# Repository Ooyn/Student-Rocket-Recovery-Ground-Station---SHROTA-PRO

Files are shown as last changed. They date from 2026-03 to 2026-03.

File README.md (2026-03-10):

# Student-Rocket-Recovery-Ground-Station---SHROTA-PRO
Shrota Pro is a custom-engineered, portable ground station PCB specifically designed to track and recover student-built rockets after touchdown. Acting as a specialized, relative GPS system, the handheld device receives critical telemetry data from the rocket and calculates its exact landing coordinates relative to the user's current position, making post-flight retrieval highly efficient.

At the heart of the system is an STM32 microcontroller responsible for real-time processing of incoming telemetry, parsing GPS data, managing sensor inputs, and driving the user interface. The board is powered by a 7.4V dual battery bus, utilizing step-down switching regulators to provide stable 5V and 3.3V rails. This robust power management ensures reliable operation of the MCU, sensitive RF equipment, and the onboard screen interface, allowing users to read relative distances and headings directly in the field. Standardized USB connectivity is also integrated for flashing firmware and serial debugging.

To accurately pinpoint positions, the board utilizes a multi-sensor navigation suite featuring an L89 GNSS module, a NEO-M8N GNSS module, and a BMM150 3-axis geomagnetic sensor that acts as a digital compass to determine the user's precise heading. For reliable long-range telemetry reception, the system incorporates a versatile radio block. It integrates RYLR998 and LLCC68 LoRa modules for robust, low-power communication links, alongside an RFD900x radio modem interface for extended range, ensuring the recovery team maintains a solid, line-of-sight connection to the downed rocket.

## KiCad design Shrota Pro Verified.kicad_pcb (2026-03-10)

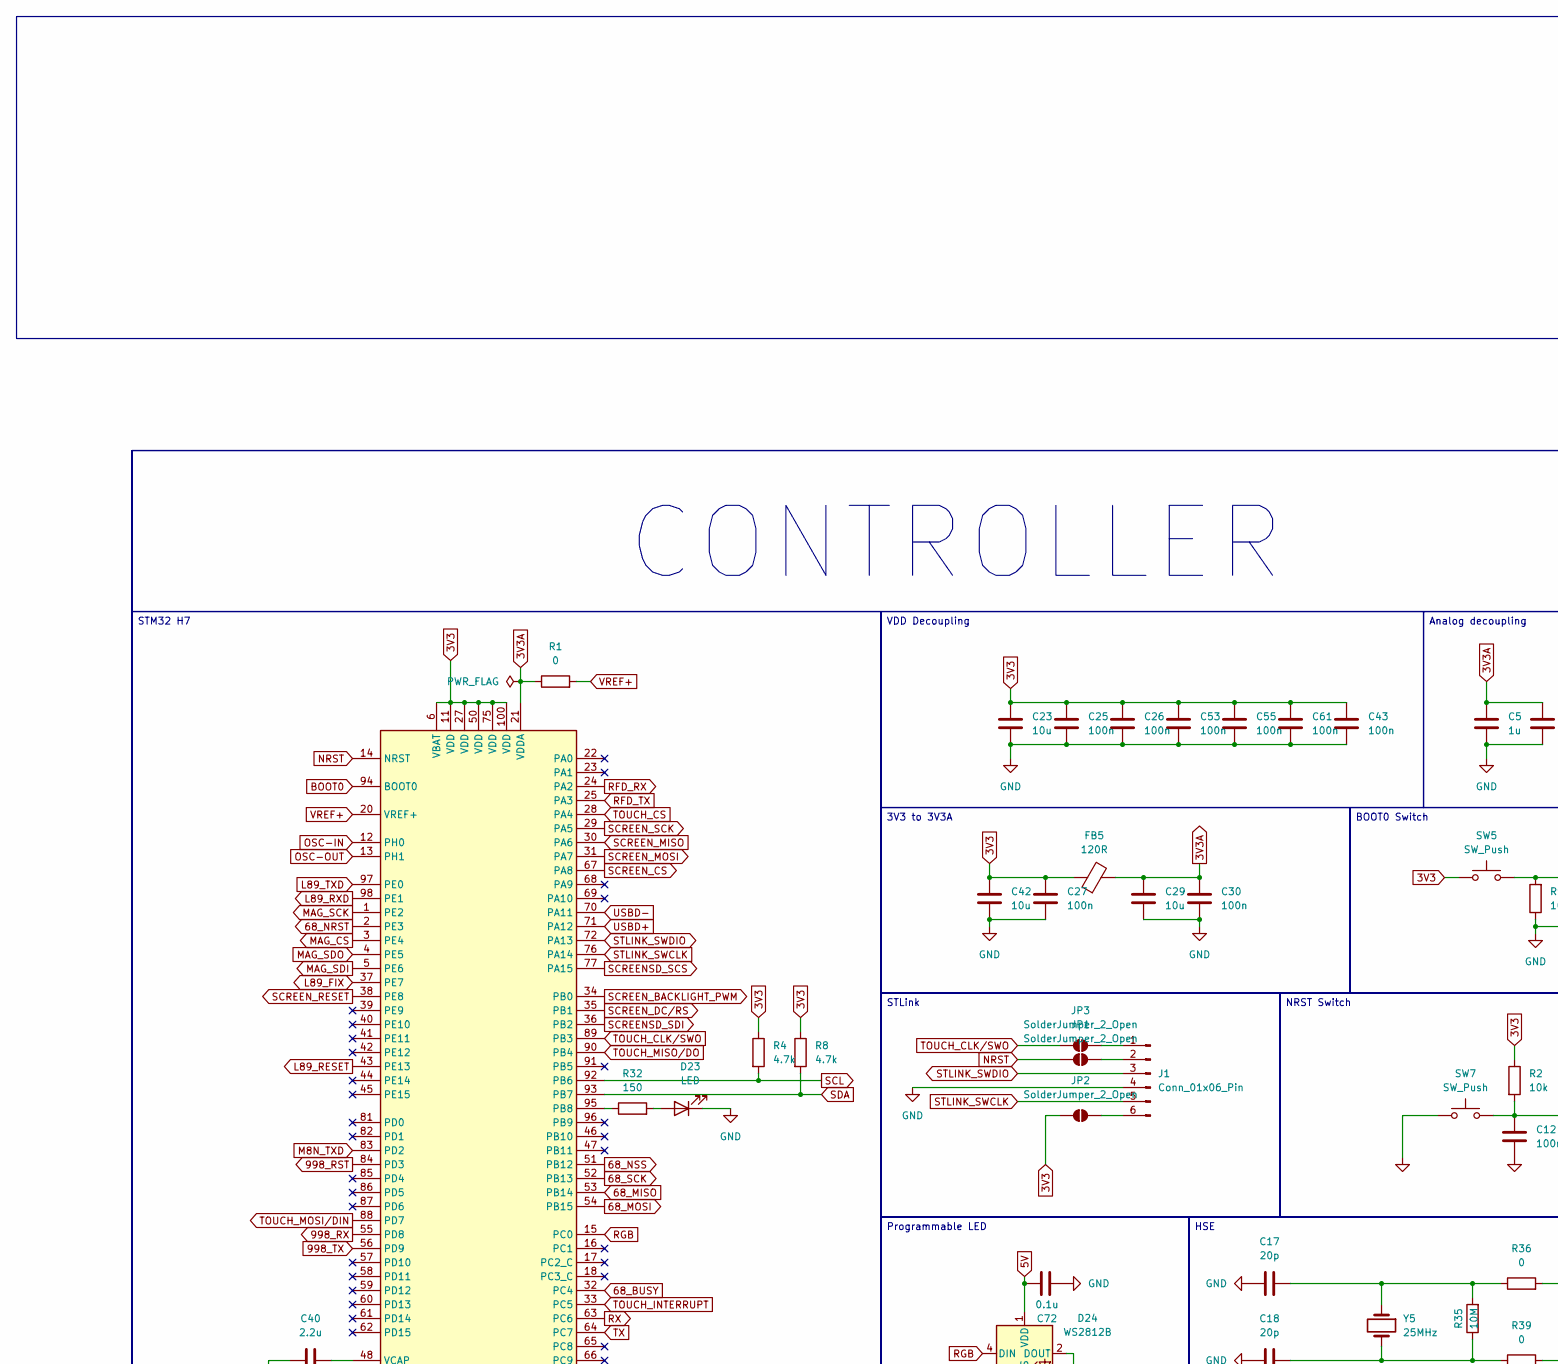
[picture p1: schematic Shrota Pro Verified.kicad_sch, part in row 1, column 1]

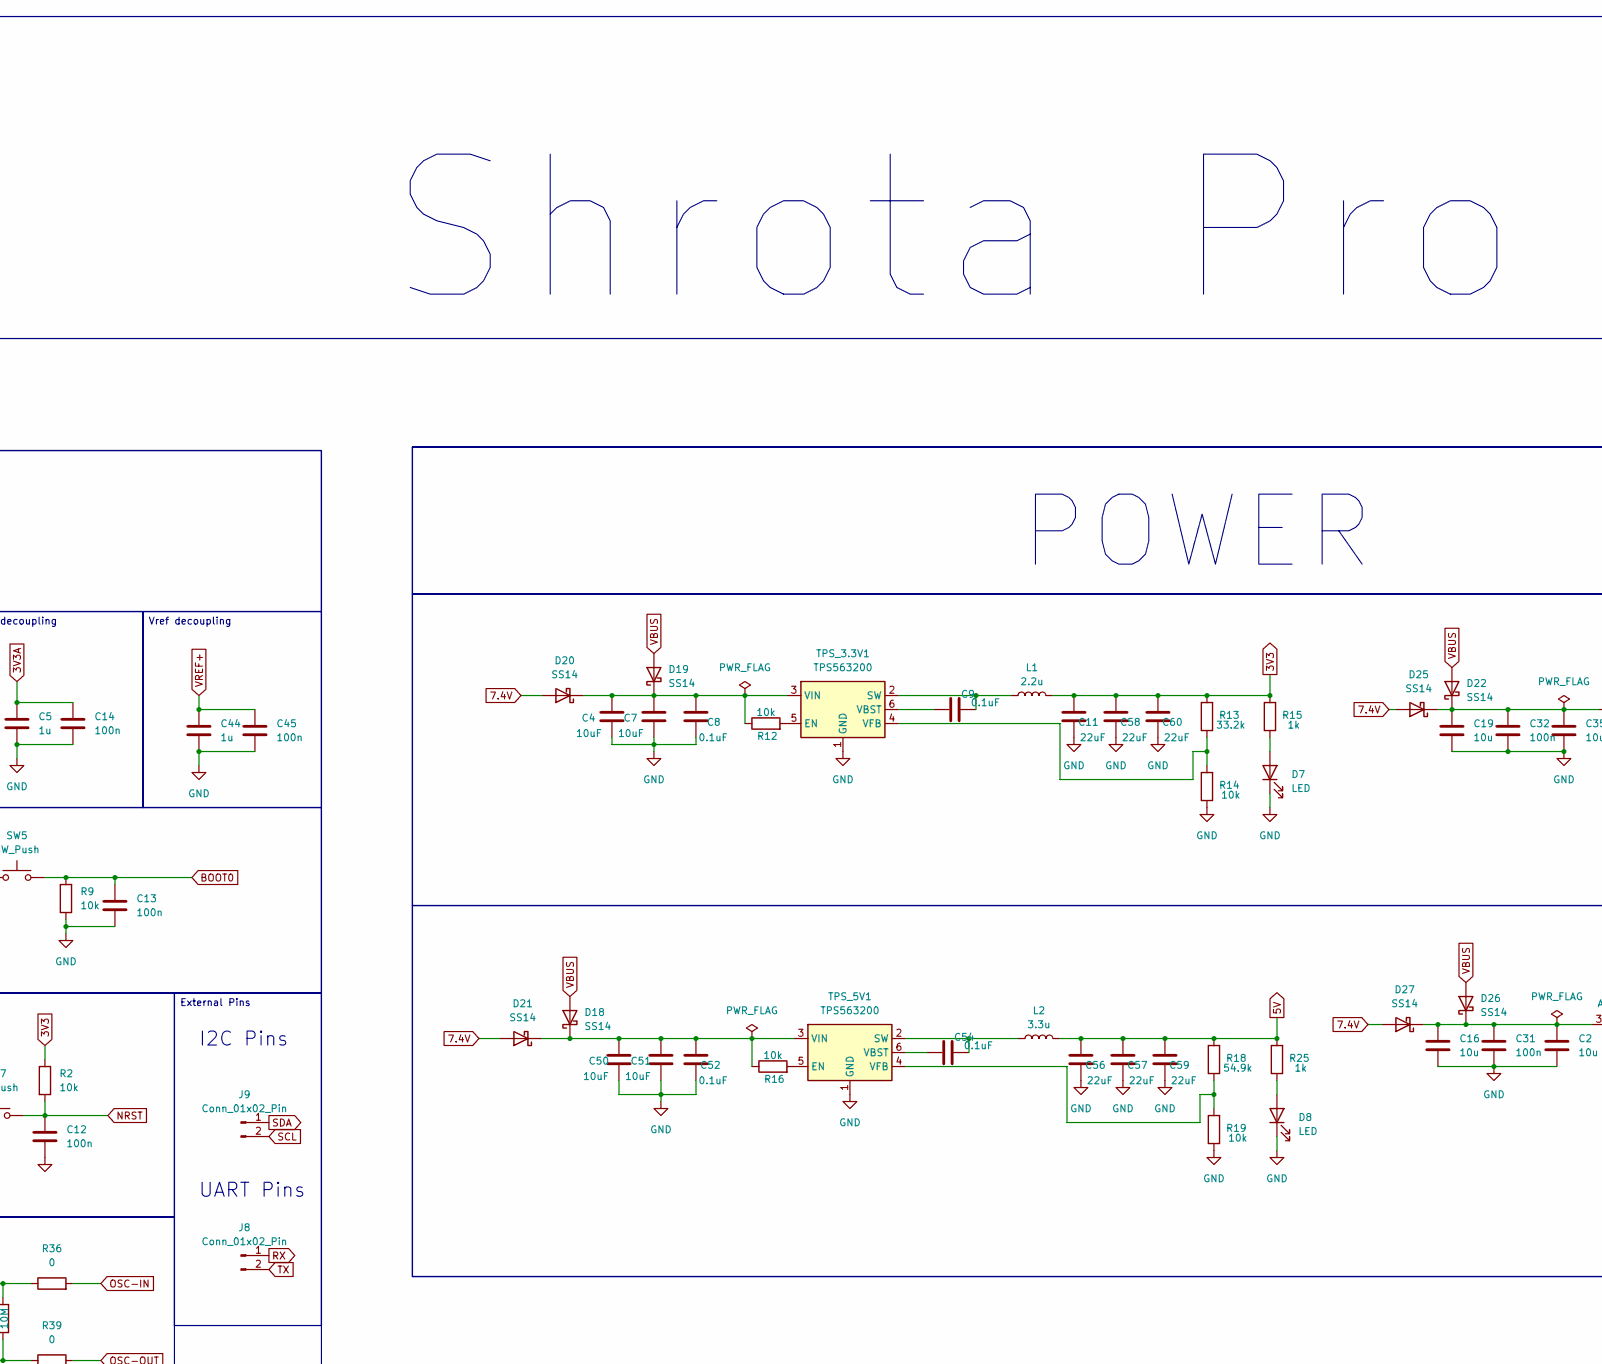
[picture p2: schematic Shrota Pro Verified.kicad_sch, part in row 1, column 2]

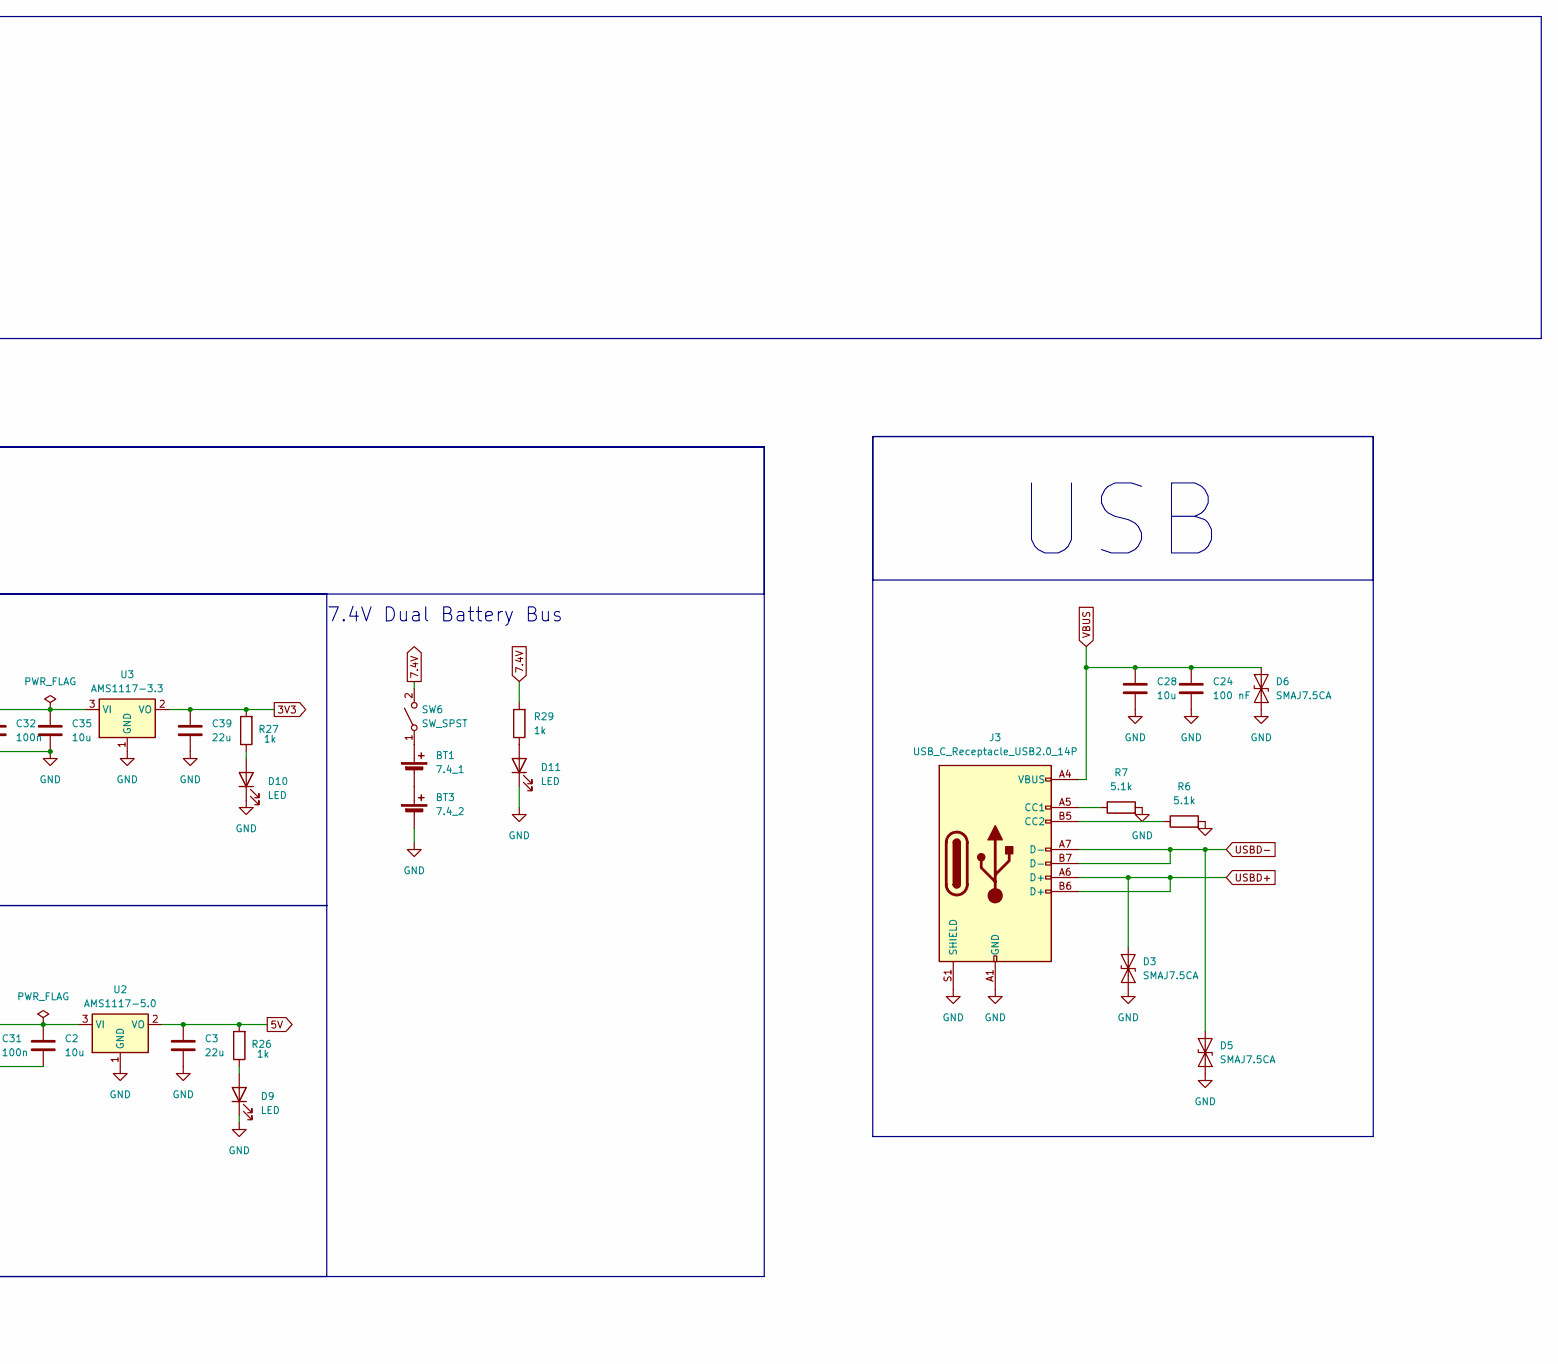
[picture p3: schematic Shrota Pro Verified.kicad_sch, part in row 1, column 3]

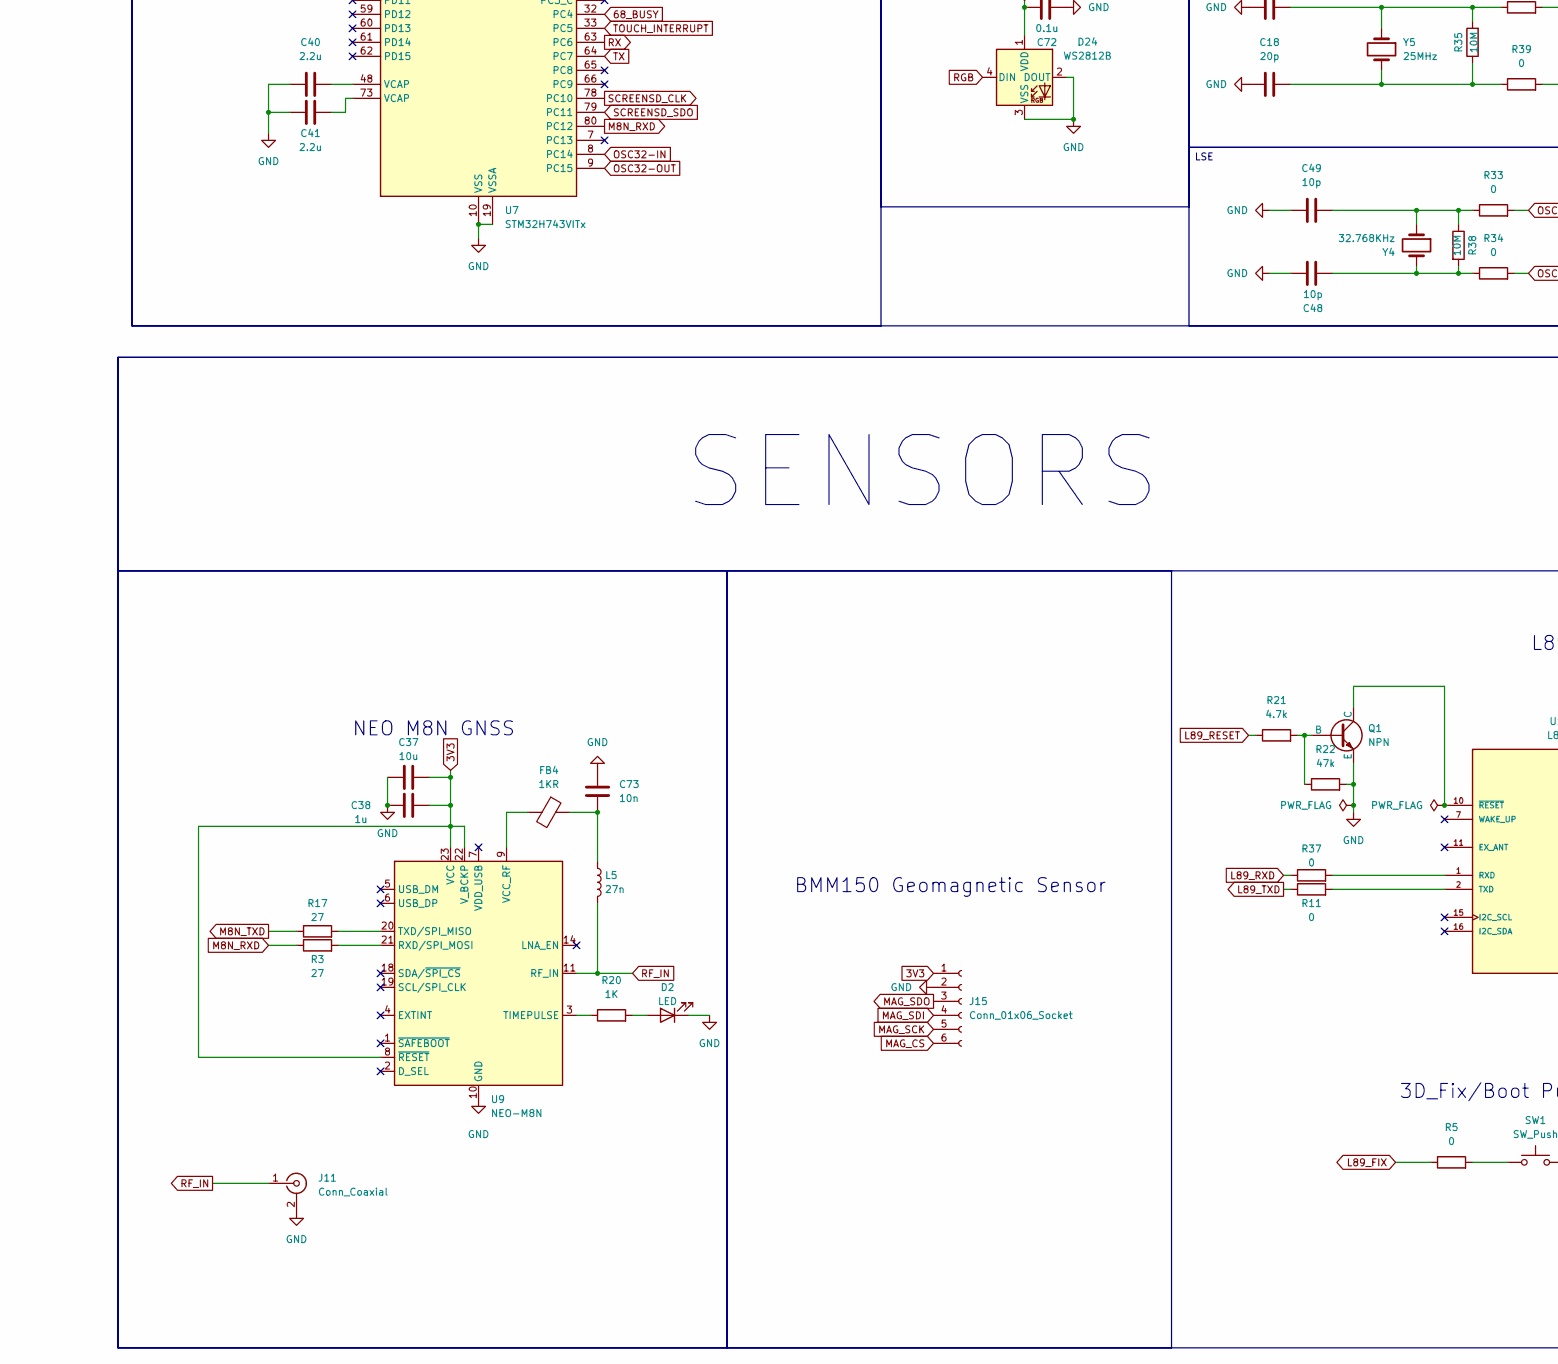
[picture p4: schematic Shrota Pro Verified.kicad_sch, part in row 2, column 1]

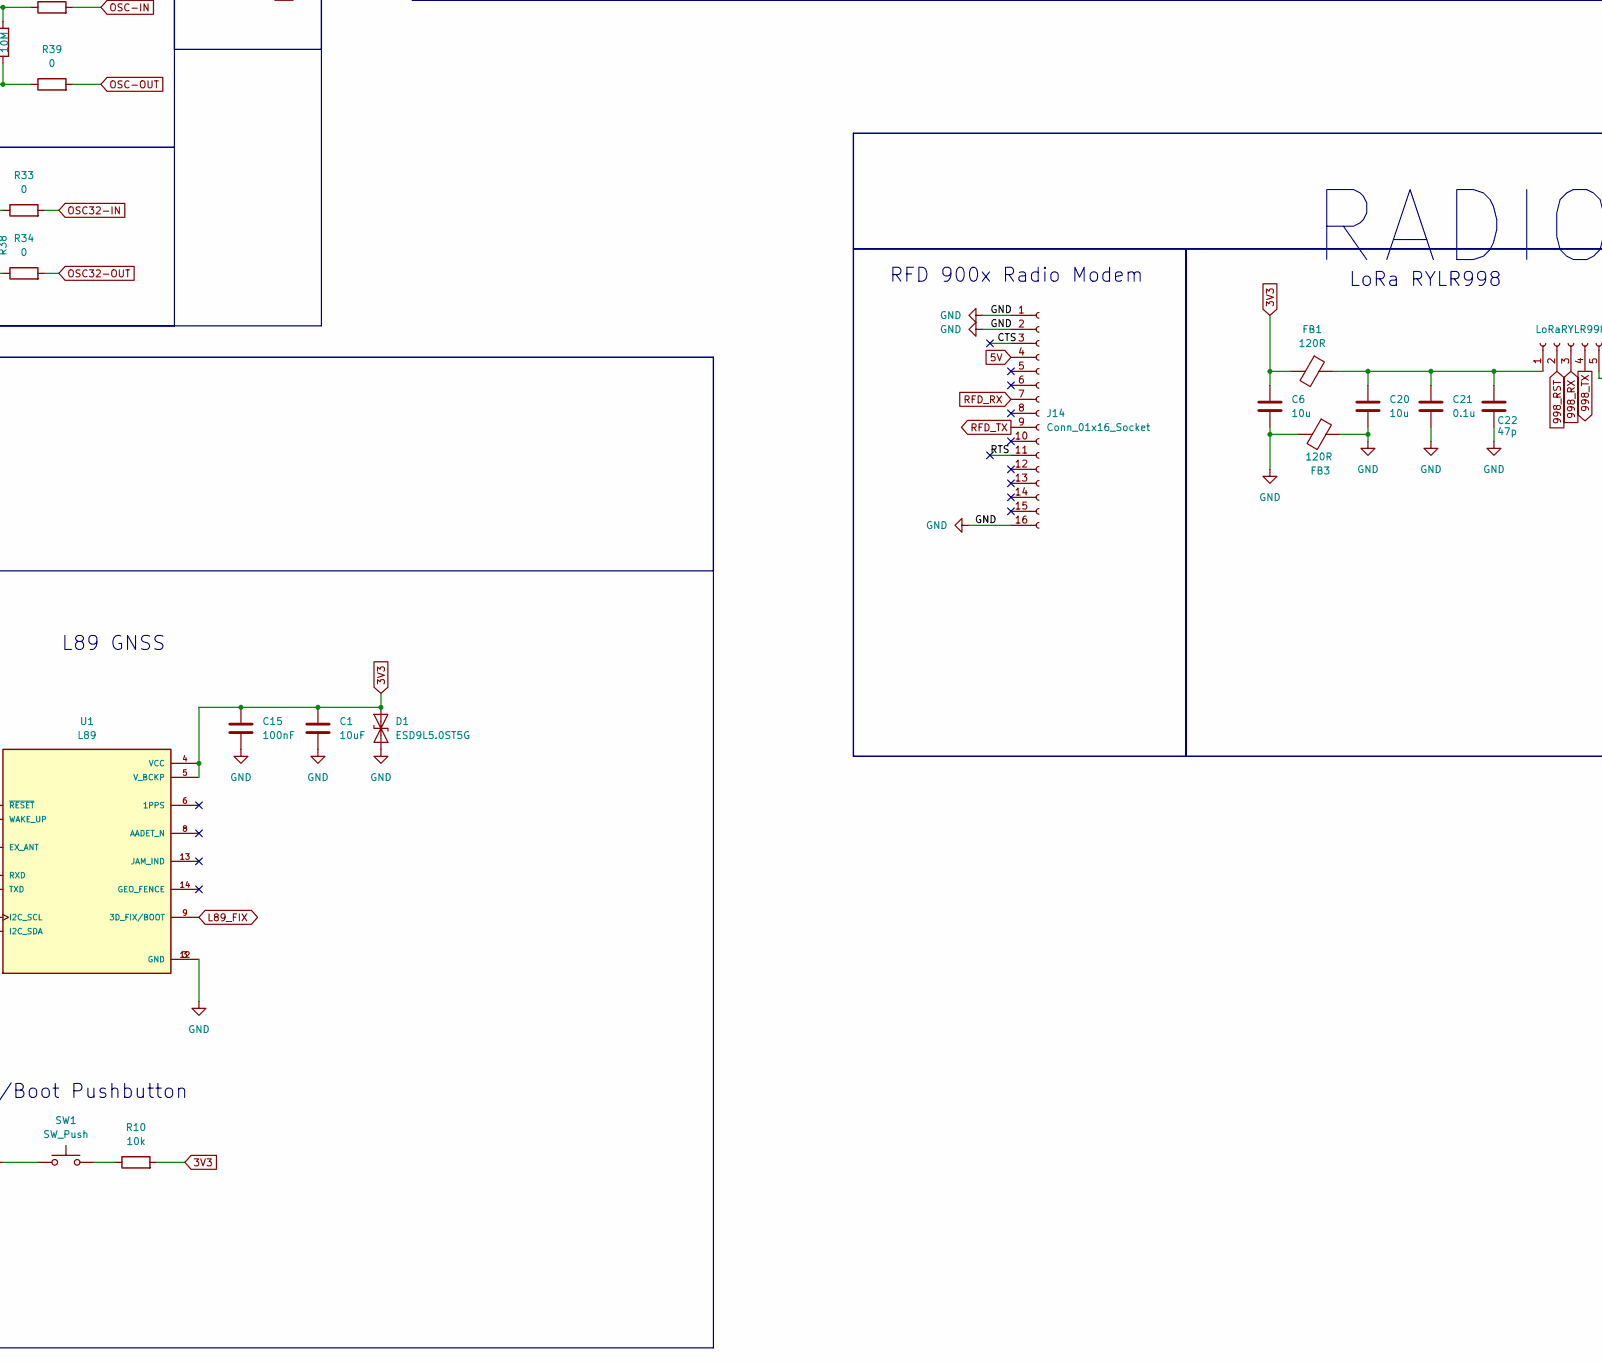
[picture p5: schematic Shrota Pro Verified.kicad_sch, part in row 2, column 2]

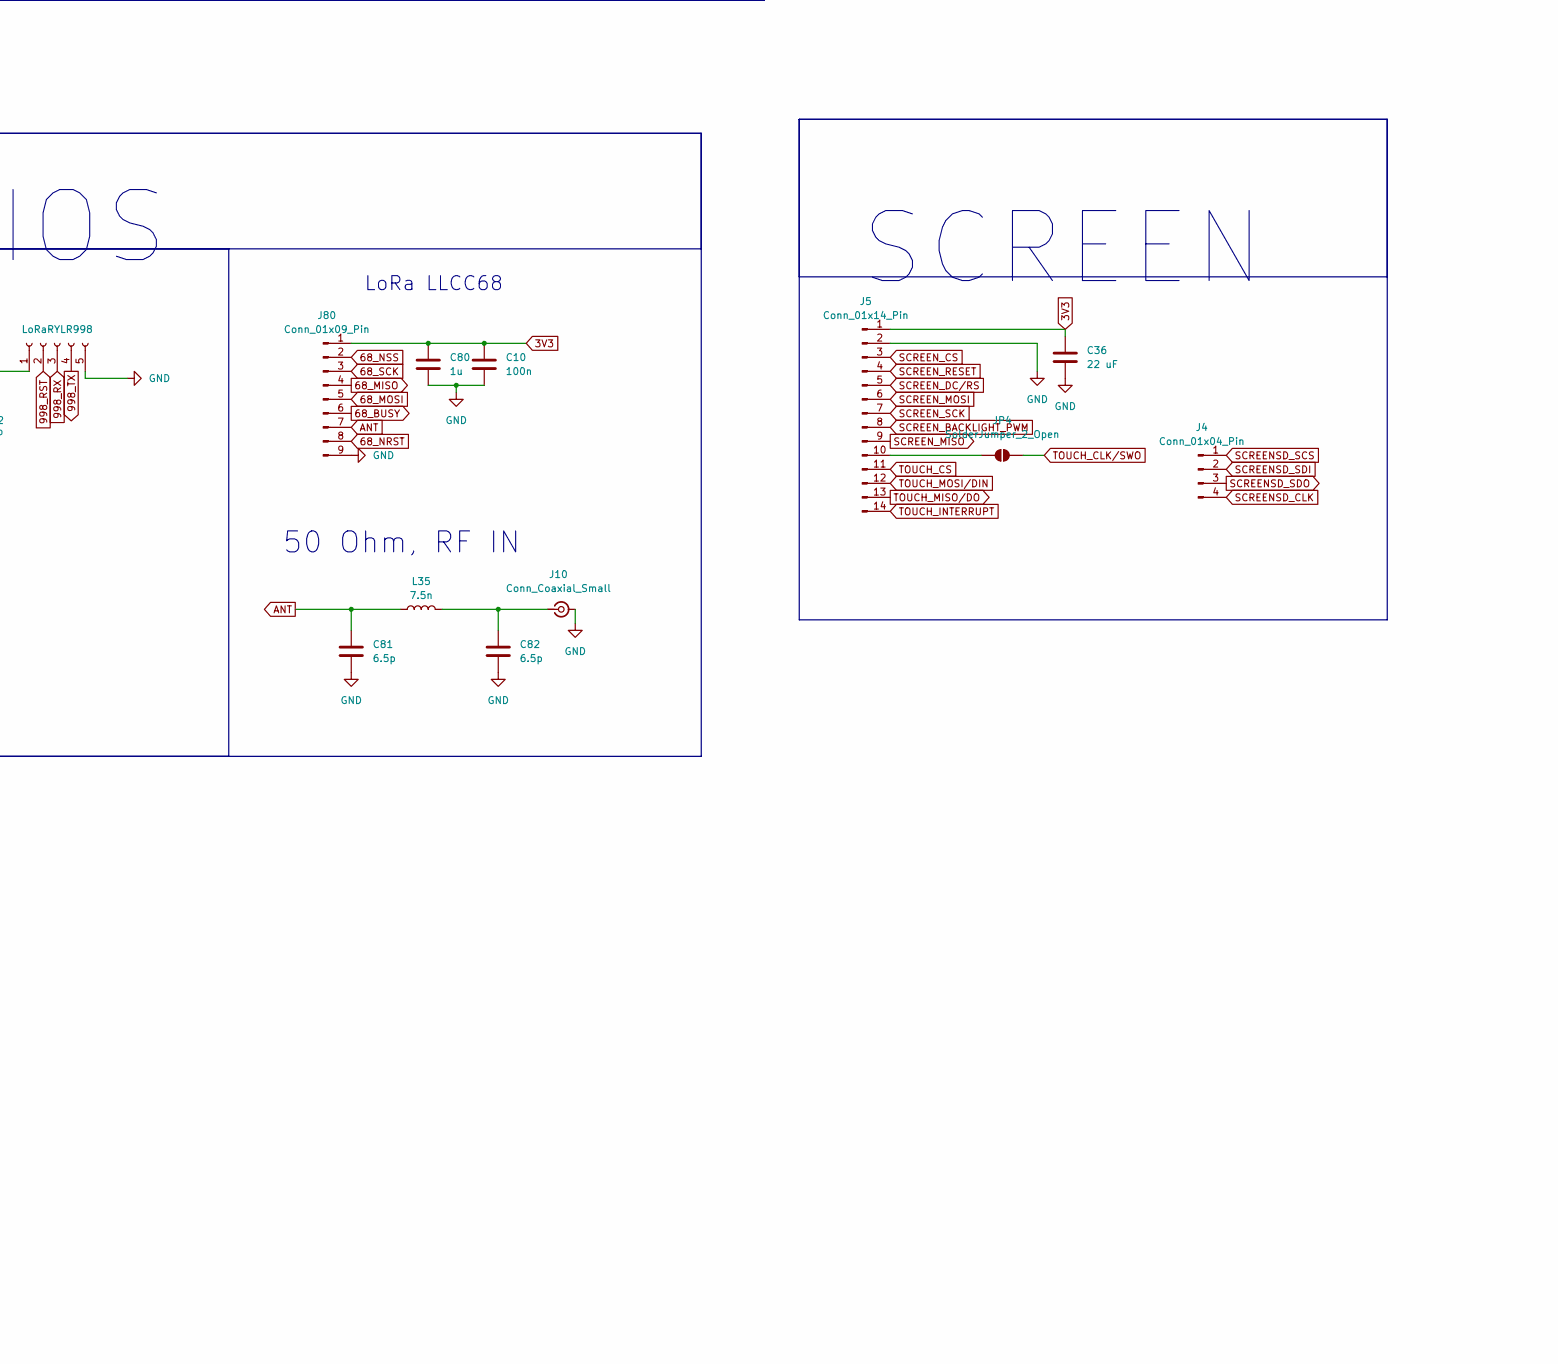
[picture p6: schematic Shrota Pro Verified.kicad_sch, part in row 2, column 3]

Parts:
BT1: 7.4_1; BatteryHolder_Keystone_1042_1x18650
BT3: 7.4_2; BatteryHolder_Keystone_1042_1x18650
C1, C4, C7, C50, C51: 10uF; C_0603_1608Metric_Pad1.08x0.95mm_HandSolder
C2, C6, C16, C19, C20, C23, C28, C29, C35, C37, C42: 10u; C_0603_1608Metric_Pad1.08x0.95mm_HandSolder
C3, C39: 22u; C_1206_3216Metric_Pad1.33x1.80mm_HandSolder
C5, C38, C44, C80: 1u; C_0603_1608Metric_Pad1.08x0.95mm_HandSolder
C8, C9, C52, C54: 0.1uF; C_0603_1608Metric_Pad1.08x0.95mm_HandSolder
C10, C12, C13, C14, C25, C26, C27, C30, C31, C32, C43, C45, C53, C55, C61: 100n; C_0603_1608Metric_Pad1.08x0.95mm_HandSolder
C11, C56, C57, C58, C59, C60: 22uF; C_1206_3216Metric_Pad1.33x1.80mm_HandSolder
C15: 100nF; C_0603_1608Metric_Pad1.08x0.95mm_HandSolder
C17, C18: 20p; C_0603_1608Metric_Pad1.08x0.95mm_HandSolder
C21, C72: 0.1u; C_0603_1608Metric_Pad1.08x0.95mm_HandSolder
C22: 47p; C_0603_1608Metric_Pad1.08x0.95mm_HandSolder
C24: 100 nF; C_0603_1608Metric_Pad1.08x0.95mm_HandSolder
C36: 22 uF; C_0603_1608Metric_Pad1.08x0.95mm_HandSolder
C40, C41: 2.2u; C_0603_1608Metric_Pad1.08x0.95mm_HandSolder
C48, C49: 10p; C_0603_1608Metric_Pad1.08x0.95mm_HandSolder
C73: 10n; C_0603_1608Metric_Pad1.08x0.95mm_HandSolder
C81, C82: 6.5p; C_0603_1608Metric_Pad1.08x0.95mm_HandSolder
D1: ESD9L5.0ST5G; D_SOD-923
D2, D7, D8, D9, D10, D11, D23: LED; LED_0603_1608Metric_Pad1.05x0.95mm_HandSolder
D3, D5, D6: SMAJ7.5CA; D_SMA
D18, D19, D20, D21, D22, D25, D26, D27: SS14; DO-214AC
D24: WS2812B; LED_WS2812B_PLCC4_5.0x5.0mm_P3.2mm
FB1, FB3, FB5: 120R; L_0603_1608Metric_Pad1.05x0.95mm_HandSolder
FB4: 1KR; L_0603_1608Metric_Pad1.05x0.95mm_HandSolder
J1: Conn_01x06_Pin; PinHeader_1x06_P2.54mm_Vertical
J2: LoRaRYLR998; PinSocket_1x05_P2.54mm_Vertical
J3: USB_C_Receptacle_USB2.0_14P; USB_C_Receptacle_GCT_USB4105-xx-A_16P_TopMnt_Horizontal
J4: Conn_01x04_Pin; PinSocket_1x04_P2.54mm_Vertical
J5: Conn_01x14_Pin; PinSocket_1x14_P2.54mm_Vertical
J8, J9: Conn_01x02_Pin; PinSocket_1x02_P2.54mm_Vertical
J10: Conn_Coaxial_Small; SMA_Amphenol_901-143_Horizontal
J11: Conn_Coaxial; U.FL_Hirose_U.FL-R-SMT-1_Vertical
J14: Conn_01x16_Socket; PinSocket_2x08_P2.54mm_Vertical
J15: Conn_01x06_Socket; PinSocket_1x06_P2.54mm_Vertical
J80: Conn_01x09_Pin; PinSocket_1x09_P2.54mm_Vertical
JP1, JP2, JP3, JP4: SolderJumper_2_Open; SolderJumper-2_P1.3mm_Open_Pad1.0x1.5mm
L1: 2.2u; L_Sunlord_SWPA6045S
L2: 3.3u; L_Sunlord_SWPA8040S
L5: 27n; L_0603_1608Metric_Pad1.05x0.95mm_HandSolder
L35: 7.5n; L_0603_1608Metric_Pad1.05x0.95mm_HandSolder
Q1: NPN; SOT-23
R1, R5, R11, R33, R34, R36, R37, R39: 0; R_0603_1608Metric_Pad0.98x0.95mm_HandSolder
R2, R9, R10, R12, R14, R16, R19: 10k; R_0603_1608Metric_Pad0.98x0.95mm_HandSolder
R3, R17: 27; R_0603_1608Metric_Pad0.98x0.95mm_HandSolder
R4, R8, R21: 4.7k; R_0603_1608Metric_Pad0.98x0.95mm_HandSolder
R6, R7: 5.1k; R_0603_1608Metric_Pad0.98x0.95mm_HandSolder
R13: 33.2k; R_0603_1608Metric_Pad0.98x0.95mm_HandSolder
R15, R25, R26, R27, R29: 1k; R_0603_1608Metric_Pad0.98x0.95mm_HandSolder
R18: 54.9k; R_0603_1608Metric_Pad0.98x0.95mm_HandSolder
R20: 1K; R_0603_1608Metric_Pad0.98x0.95mm_HandSolder
R22: 47k; R_0603_1608Metric_Pad0.98x0.95mm_HandSolder
R32: 150; R_0603_1608Metric_Pad0.98x0.95mm_HandSolder
R35, R38: 10M; R_0603_1608Metric
SW1: SW_Push; SW_PUSH_6mm
SW5, SW7: SW_Push; SW_Push_1P1T_NO_CK_KMR2
SW6: SW_SPST; SW_DIP_SPSTx01_Slide_9.78x4.72mm_W8.61mm_P2.54mm
TPS_3.3V1, TPS_5V1: TPS563200; SOT-23-6
U1: L89; XCVR_L89; PARTREV 1.1
U2: AMS1117-5.0; SOT-223-3_TabPin2
U3: AMS1117-3.3; SOT-223-3_TabPin2
U7: STM32H743VITx; LQFP-100_14x14mm_P0.5mm
U9: NEO-M8N; ublox_NEO
Y4: 32.768KHz; XTAL_ABS07AIG-32.768KHZ-1-T
Y5: 25MHz; XTAL_ABLS-25.000MHZ-B2F-T

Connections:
3V3: C1.1, C6.1, C10.1, C11.2, C15.1, C23.1, C25.1, C26.1, C27.1, C36.1, C37.1, C38.1, C39.1, C42.1, C43.1, C53.1, C55.1, C58.2, C60.2, C61.1, C80.1, D1.2 (A2), FB1.2, FB5.1, J5.1, J15.1, J80.1, JP2.1 (A), L1.2, R2.1, R4.1, R8.1, R10.2, R13.2, R15.2, R27.2, SW5.1, U1.4 (VCC), U1.5 (V_BCKP), U3.2 (VO), U7.6 (VBAT), U7.11 (VDD), U7.27 (VDD), U7.50 (VDD), U7.75 (VDD), U7.100 (VDD), U9.8 (~RESET), U9.22 (V_BCKP), U9.23 (VCC)
3V3A: C5.1, C14.1, C29.1, C30.1, FB5.2, R1.1, U7.21 (VDDA)
5V: C3.1, C56.2, C57.2, C59.2, C72.2, D24.1 (VDD), J14.4, L2.2, R18.2, R25.2, R26.2, U2.2 (VO)
7.4V: D20.2 (A), D21.2 (A), D25.2 (A), D27.2 (A), R29.2, SW6.2 (B)
68_BUSY: J80.6, U7.32 (PC4)
68_MISO: J80.4, U7.53 (PB14)
68_MOSI: J80.5, U7.54 (PB15)
68_NRST: J80.8, U7.2 (PE3)
68_NSS: J80.2, U7.51 (PB12)
68_SCK: J80.3, U7.52 (PB13)
998_RST: J2.2, U7.84 (PD3)
998_RX: J2.3, U7.55 (PD8)
998_TX: J2.4, U7.56 (PD9)
/CTS: J14.3
/RTS: J14.11
ANT: C81.1, J80.7, L35.1
BOOT0: C13.1, R9.2, SW5.2, U7.94 (BOOT0)
GND: BT3.2 (-), C1.2, C2.2, C3.2, C4.1, C5.2, C6.2, C7.1, C8.1, C10.2, C11.1, C12.2, C13.2, C14.2, C15.2, C16.2, C17.1, C18.1, C19.2, C20.2, C21.2, C22.2, C23.2, C24.2, C25.2, C26.2, C27.2, C28.2, C29.2, C30.2, C31.2, C32.2, C35.2, C36.2, C37.2, C38.2, C39.2, C40.1, C41.2, C42.2, C43.2, C44.2, C45.2, C48.2, C49.2, C50.1, C51.1, C52.1, C53.2, C55.2, C56.1, C57.1, C58.1, C59.1, C60.1, C61.2, C72.1, C73.1, C80.2, C81.2, C82.2, D1.1 (A1), D2.1 (K), D3.1 (A1), D5.1 (A1), D6.1 (A1), D7.1 (K), D8.1 (K), D9.1 (K), D10.1 (K), D11.1 (K), D23.1 (K), D24.2 (DOUT), D24.3 (VSS), FB3.1, FB3.2, J1.4, J2.5, J3.A1 (GND), J3.A12 (GND), J3.B1 (GND), J3.B12 (GND), J3.S1 (SHIELD), J5.2, J10.2 (Ext), J11.2 (Ext), J14.1, J14.2, J14.16, J15.2, J80.9, Q1.3 (E), R6.2, R7.2, R9.1, R14.1, R19.1, R22.2, SW7.1, TPS_3.3V1.1 (GND), TPS_5V1.1 (GND), U1.3 (GND), U1.12 (GND), U2.1 (GND), U3.1 (GND), U7.10 (VSS), U7.19 (VSSA), U7.26 (VSS), U7.49 (VSS), U7.74 (VSS), U7.99 (VSS), U9.10 (GND), U9.12 (GND), U9.13 (GND), U9.24 (GND)
L89_FIX: R5.1, U1.9 (3D_FIX/BOOT), U7.37 (PE7)
L89_RESET: R21.1, U7.43 (PE13)
L89_RXD: R37.1, U7.98 (PE1)
L89_TXD: R11.1, U7.97 (PE0)
M8N_RXD: R3.1, U7.80 (PC12)
M8N_TXD: R17.1, U7.83 (PD2)
MAG_CS: J15.6, U7.3 (PE4)
MAG_SCK: J15.5, U7.1 (PE2)
MAG_SDI: J15.4, U7.5 (PE6)
MAG_SDO: J15.3, U7.4 (PE5)
NRST: C12.1, JP1.1 (A), R2.2, SW7.2, U7.14 (NRST)
unnamed: BT1.1 (+), SW6.1 (A)
unnamed: BT1.2 (-), BT3.1 (+)
unnamed: C17.2, R35.2, R36.1, Y5.1
unnamed: C18.2, R35.1, R39.1, Y5.2
unnamed: C40.2, U7.48 (VCAP)
unnamed: C41.1, U7.73 (VCAP)
unnamed: C48.1, R34.1, R38.2, Y4.2
unnamed: C49.1, R33.1, R38.1, Y4.1
unnamed: C73.2, FB4.1, L5.1
unnamed: D2.2 (A), R20.2
unnamed: D7.2 (A), R15.1
unnamed: D8.2 (A), R25.1
unnamed: D9.2 (A), R26.1
unnamed: D10.2 (A), R27.1
unnamed: D11.2 (A), R29.1
unnamed: C50.2, C51.2, C52.2, D18.1 (K), D21.1 (K), R16.1, TPS_5V1.3 (VIN)
unnamed: C4.2, C7.2, C8.2, D19.1 (K), D20.1 (K), R12.1, TPS_3.3V1.3 (VIN)
unnamed: C19.1, C32.1, C35.1, D22.1 (K), D25.1 (K), U3.3 (VI)
unnamed: D23.2 (A), R32.2
unnamed: C2.1, C16.1, C31.1, D26.1 (K), D27.1 (K), U2.3 (VI)
unnamed: J1.1, JP3.2 (B)
unnamed: J1.2, JP1.2 (B)
unnamed: J1.6, JP2.2 (B)
unnamed: C20.1, C21.1, C22.1, FB1.1, J2.1
unnamed: J3.A5 (CC1), R7.1
unnamed: J3.B5 (CC2), R6.1
unnamed: J5.10, JP4.1 (A)
unnamed: C82.1, J10.1 (In), L35.2
unnamed: Q1.2 (B), R21.2, R22.1
unnamed: Q1.1 (C), U1.10 (~RESET)
unnamed: R5.2, SW1.1
unnamed: R10.1, SW1.2
unnamed: R12.2, TPS_3.3V1.5 (EN)
unnamed: C9.1, L1.1, TPS_3.3V1.2 (SW)
unnamed: C9.2, TPS_3.3V1.6 (VBST)
unnamed: R13.1, R14.2, TPS_3.3V1.4 (VFB)
unnamed: R16.2, TPS_5V1.5 (EN)
unnamed: C54.1, L2.1, TPS_5V1.2 (SW)
unnamed: C54.2, TPS_5V1.6 (VBST)
unnamed: R18.1, R19.2, TPS_5V1.4 (VFB)
unnamed: R37.2, U1.1 (RXD)
unnamed: R11.2, U1.2 (TXD)
unnamed: R32.1, U7.95 (PB8)
unnamed: R3.2, U9.21 (RXD/SPI_MOSI)
unnamed: R20.1, U9.3 (TIMEPULSE)
unnamed: R17.2, U9.20 (TXD/SPI_MISO)
unnamed: FB4.2, U9.9 (VCC_RF)
OSC32-IN: R33.2, U7.8 (PC14)
OSC32-OUT: R34.2, U7.9 (PC15)
OSC-IN: R36.2, U7.12 (PH0)
OSC-OUT: R39.2, U7.13 (PH1)
RFD_RX: J14.7, U7.24 (PA2)
RFD_TX: J14.9, U7.25 (PA3)
RF_IN: J11.1 (In), L5.2, U9.11 (RF_IN)
RGB: D24.4 (DIN), U7.15 (PC0)
RX: J8.1, U7.63 (PC6)
SCL: J9.2, R4.2, U7.92 (PB6)
SCREENSD_CLK: J4.4, U7.78 (PC10)
SCREENSD_SCS: J4.1, U7.77 (PA15)
SCREENSD_SDI: J4.2, U7.36 (PB2)
SCREENSD_SDO: J4.3, U7.79 (PC11)
SCREEN_BACKLIGHT_PWM: J5.8, U7.34 (PB0)
SCREEN_CS: J5.3, U7.67 (PA8)
SCREEN_DC/RS: J5.5, U7.35 (PB1)
SCREEN_MISO: J5.9, U7.30 (PA6)
SCREEN_MOSI: J5.6, U7.31 (PA7)
SCREEN_RESET: J5.4, U7.38 (PE8)
SCREEN_SCK: J5.7, U7.29 (PA5)
SDA: J9.1, R8.2, U7.93 (PB7)
STLINK_SWCLK: J1.5, U7.76 (PA14)
STLINK_SWDIO: J1.3, U7.72 (PA13)
TOUCH_CLK/SWO: JP3.1 (A), JP4.2 (B), U7.89 (PB3)
TOUCH_CS: J5.11, U7.28 (PA4)
TOUCH_INTERRUPT: J5.14, U7.33 (PC5)
TOUCH_MISO/DO: J5.13, U7.90 (PB4)
TOUCH_MOSI/DIN: J5.12, U7.88 (PD7)
TX: J8.2, U7.64 (PC7)
USBD+: D3.2 (A2), J3.A6 (D+), J3.B6 (D+), U7.71 (PA12)
USBD-: D5.2 (A2), J3.A7 (D-), J3.B7 (D-), U7.70 (PA11)
VBUS: C24.1, C28.1, D6.2 (A2), D18.2 (A), D19.2 (A), D22.2 (A), D26.2 (A), J3.A4 (VBUS), J3.A9 (VBUS), J3.B4 (VBUS), J3.B9 (VBUS)
VREF+: C44.1, C45.1, R1.2, U7.20 (VREF+)

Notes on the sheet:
BMM150 Geomagnetic Sensor
LoRa LLCC68
L89 GNSS
USB
SCREEN
UART Pins
NEO M8N GNSS
50 Ohm, RF IN
LoRa RYLR998
3D_Fix/Boot Pushbutton
I2C Pins
RFD 900x Radio Modem
RADIOS
POWER
Shrota Pro
CONTROLLER
SENSORS
7.4V Dual Battery Bus
BOOT0 Switch
STM32 H7
NRST Switch
STLink
HSE
Programmable LED
VDD Decoupling
External Pins
Vref decoupling
3V3 to 3V3A
LSE
Analog decoupling

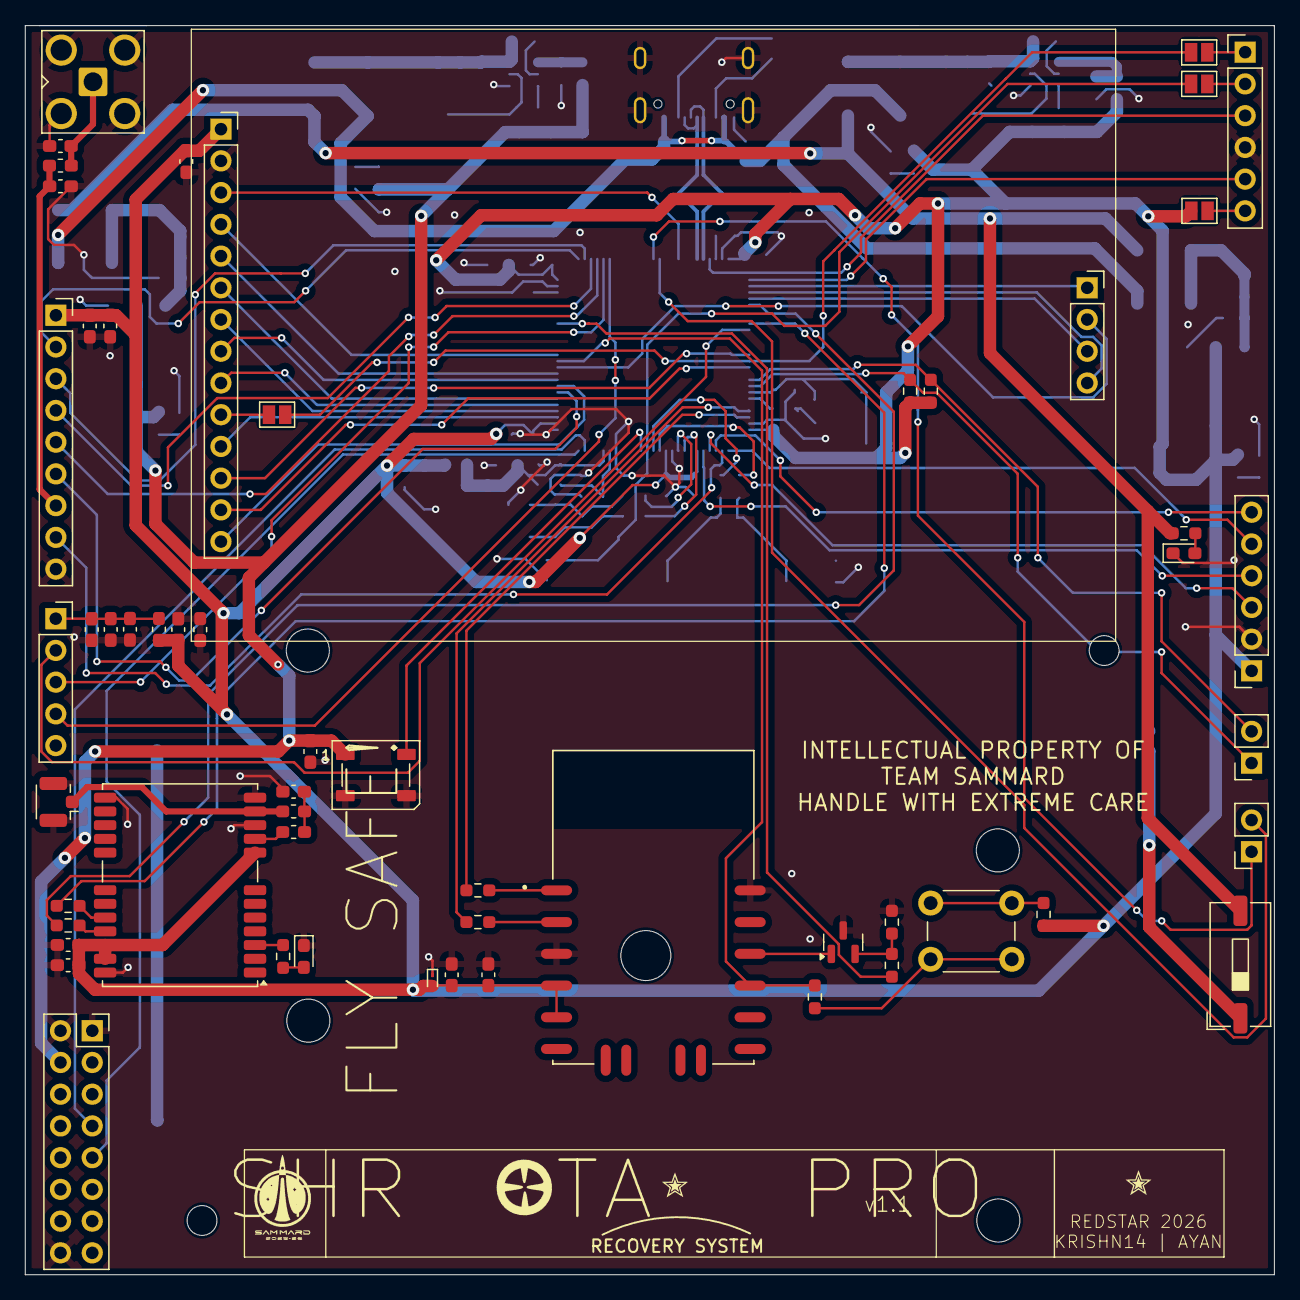
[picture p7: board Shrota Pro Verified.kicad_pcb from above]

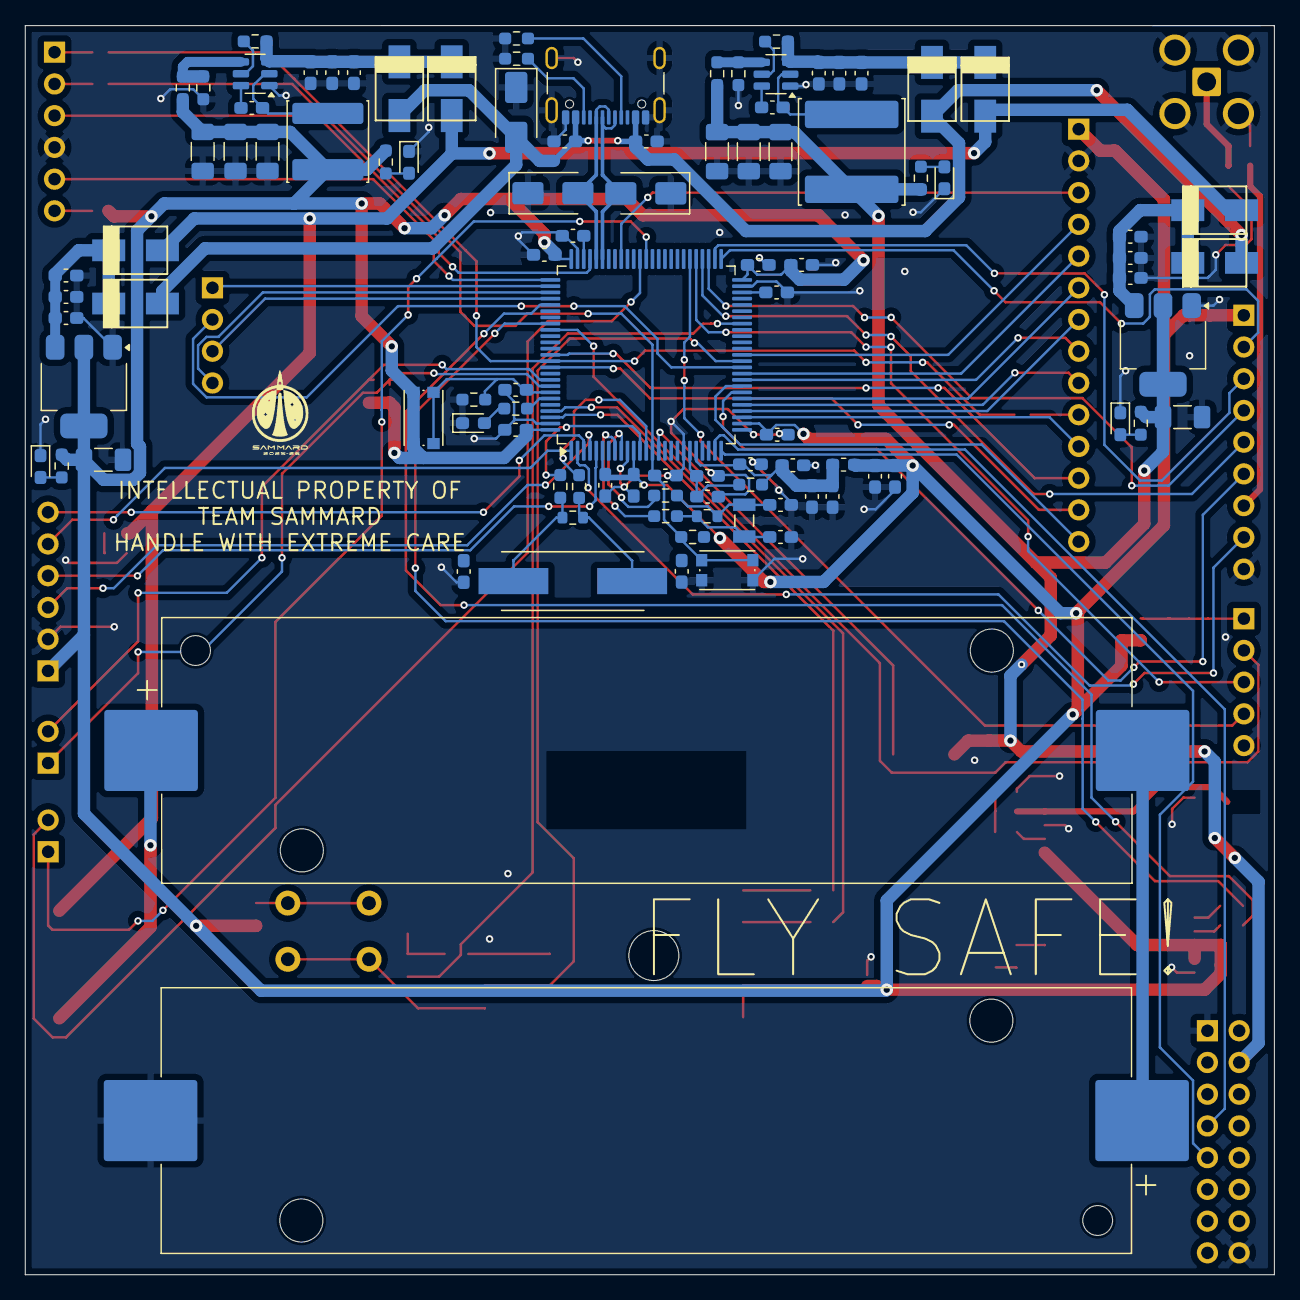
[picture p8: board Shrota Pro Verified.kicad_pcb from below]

Board: 2 copper layers, 100.0 x 100.0 mm, 156 parts (100 on the bottom side), 108 nets.
